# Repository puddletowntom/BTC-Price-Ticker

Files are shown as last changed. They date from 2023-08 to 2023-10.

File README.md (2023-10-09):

# Bitcoin Metrics Tracker



# Introduction

The Bitcoin metrics tracker was designed to sit near your desktop and keep an eye on several key important metrics on the Bitcoin network. These metrics include the Bitcoin price, the total Bitcoin marketcap, the total Bitcoin supply, the hash rate of the network, the current number of Bitcoins rewarded per block, the estimated time interval between blocks mined, the number of blocks mined so far and the remaining blocks left to mine in the current 4 year cycle. It uses Wi-Fi to connect to Blockchain.com to update the metrics at regular intervals. There is no need to hard code Wi-Fi credentials as there is a WPS setup for synchronisation with your router. Router credentials are then saved to flash memory via NVS so that you only have to do it one time. The green light on the screen indicates if Wi-Fi is connected. The green light will switch off if disconnected with the router. It will try to reconnect when it disconnects. The spinner around the green light is when the data is updating. 

# Parts Included

For the 3D printed case I have included the 3mf files. This project includes the following,

- RGB (565) display with ST7701s IC driver,
- ESP32-S3 R8 (8MB PSRAM) and 4MB of flash memory,
- Charging circuitry on PCB,
- USB-C,
- 3D print case

# Development Board

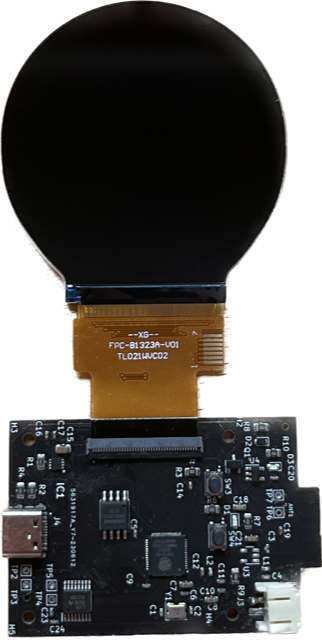
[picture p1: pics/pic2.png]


# Software 

- Kicad for PCB files,
- Fusion 360 for STL files,
- ESP-IDF for development environment,
- SquareLine Studio for display graphics

# Pinout

You can find the entire pinout with the schematic provided. But a brief overview is as follows,

Buttons

- TP6 to TP7 for Power button,
- SW3 - Reset button,
- SW4 - Boot button

# WPS

When you first turn on the device you will be met with the WPS screen. This is so you can connect to your router without needing to type your Wi-Fi credentials. So you need to press your WPS button on your router to sync it with the device. If it fails to move on from the WPS screen, unplug the device and plug it back in and press the WPS button on the router again. If it syncs with your router it will move on to the next screen which is a Bitcoin logo saying setup. 

# Programming the device

There are two modes for the ESP32-S3, download mode (upload program) and run mode (code running). To put the board in program mode press and hold the button SW4 (boot) and while this is still being held press the SW3 (reset) button. To put the board into run mode just press SW3 (reset) button once or alternatively just unplug the device. 

- idf.py set-target ESP32-S3 (only need to do this once)
- idf.py build (rebuild when you make changes to code)
- idf.py flash -p COM8 -b 921600 monitor (download code while monitoring)

# Restore credentials

If you want to change the Wi-Fi credentials to a new router, I have put in a define for restoring credentials. To do this you need to uncomment the following and build+download+run this code to clear credentials. 

#define CONFIG_RESTORE

You then need to comment it out again and download it to revert to original code. 

//#define CONFIG_RESTORE

# Further Work

The device currently doesnt have a GPIO reset button which means that once you sync the device with a Wi-Fi router via WPS you cant join a different router unless you reprogram the board with the config restore feature.

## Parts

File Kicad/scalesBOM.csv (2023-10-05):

Source: | C:\Users\ronan\Documents\KiCad\WSUpgrade\WeightingScales.kicad_sch
Date: | 10/06/2023 12:21:17
Tool: | Eeschema 7.0.1
Generator: | C:\Program Files\KiCad\7.0\bin\scripting\plugins/bom_csv_grouped_by_value_with_fp.py
Component Count: | 63
Ref | Qnty | Value | Cmp name | Footprint | Description | Vendor | DNP
AE1 | 1 | Antenna_Loop | Antenna_Loop | ESP_Antenna:ESPRESSIF_ESP32_MIFA_2.4GHz_Right | Loop antenna
C1, C2 | 2 | 22pF | C | Capacitor_SMD:C_0402_1005Metric | Unpolarized capacitor
C3, C4 | 2 | 3p3 | C | Capacitor_SMD:C_0402_1005Metric | Unpolarized capacitor
C5, C16 | 2 | 100nF | C | Capacitor_SMD:C_0402_1005Metric | Unpolarized capacitor
C6, C10, C17, C19 | 4 | 1uF | C | Capacitor_SMD:C_0402_1005Metric | Unpolarized capacitor
C7, C8 | 2 | 10uF | C | Capacitor_SMD:C_0603_1608Metric | Unpolarized capacitor
C9, C11, C12, C14, C23, C24 | 6 | 0.1uF | C | Capacitor_SMD:C_0402_1005Metric | Capacitor symbol for simulation only
C15 | 1 | 1uF | C | Capacitor_SMD:C_0805_2012Metric | Unpolarized capacitor
C18, C21 | 2 | 4.7uF | C | Capacitor_SMD:C_0603_1608Metric | Unpolarized capacitor
C20 | 1 | 2.2uF | C | Capacitor_SMD:C_0402_1005Metric | Unpolarized capacitor
D1, D3 | 2 | LED | LED | LED_SMD:LED_0603_1608Metric | Light emitting diode
D2 | 1 | D_Schottky | D_Schottky | Diode_SMD:D_0603_1608Metric | Schottky diode
H2, H3, H4, H5 | 4 | MountingHole | MountingHole | MountingHole:MountingHole_2.2mm_M2 | Mounting Hole without connection
IC1 | 1 | CAT4004AHU2-GT3 | CAT4004AHU2-GT3 | CAT4004A-libraries:SON50P200X200X55-9N | Driver,LED,4-channel,EZDim,UDFN8 ON Semiconductor CAT4004AHU2-GT3, LED Display Driver, 4 V, 8-Pin UDFN
IC2 | 1 | ADS1230IPWR | ADS1230IPWR | ADS1230IPWR:SOP65P640X120-16N | 20-Bit, 80SPS, 1-Ch Delta-Sigma ADC for Resistive Bridge Sensors & Weigh Scales
IC3 | 1 | ESP32-S3R8 | ESP32-S3R8 | ESP32-S3R8:QFN40P700X700X90-57N-D | WiFi Modules - 802.11 SMD IC, Dual-Core MCU, Wi-Fi 2.4G & BLE 5.0 Combo, 8 MB Octal SPI PSRAM, QFN 56-pin, 7*7 mm
J2 | 1 | FH34SRJ-40S-0.5SH(50) | FH34SRJ-40S-0.5SH(50) | FH34SRJ-40S-0.5SH_50_:HRS_FH34SRJ-40S-0.5SH(50)
J3 | 1 | Conn_01x02 | Conn_01x02 | Connector_JST:JST_PH_S2B-PH-SM4-TB_1x02-1MP_P2.00mm_Horizontal | Generic connector, single row, 01x02, script generated (kicad-library-utils/schlib/autogen/connector/)
J4 | 1 | TYPE-C-31-M-12 | TYPE-C-31-M-12 | TYPE-C-31-M-12:HRO_TYPE-C-31-M-12
L1 | 1 | 2n2 | L | Inductor_SMD:L_0402_1005Metric | Inductor
L2 | 1 | 2nH | L | Inductor_SMD:L_0402_1005Metric | Inductor
Q1 | 1 | AO3401A | AO3401A | Package_TO_SOT_SMD:SOT-23 | -4.0A Id, -30V Vds, P-Channel MOSFET, SOT-23
R1 | 1 | 3.74k | R | Resistor_SMD:R_0805_2012Metric | Resistor
R2, R4 | 2 | 5.1k | R | Resistor_SMD:R_0805_2012Metric | Resistor
R3, R6, R8 | 3 | 10k | R | Resistor_SMD:R_0805_2012Metric | Resistor
R7, R10 | 2 | 1k | R | Resistor_SMD:R_0805_2012Metric | Resistor
R9 | 1 | 2k | R | Resistor_SMD:R_0805_2012Metric | Resistor
SW3, SW4 | 2 | PTS810_SJM_250_SMTR_LFS | PTS810_SJM_250_SMTR_LFS | PTS810_SJM_250_SMTR_LFS:SW_PTS810_SJM_250_SMTR_LFS
TP1, TP2, TP3, TP4, TP5, TP6, TP7, TP19, TP20 | 9 | TestPoint | TestPoint | Connector_Pin:Pin_D0.7mm_L6.5mm_W1.8mm_FlatFork | test point
U2 | 1 | W25Q32JVSS | W25Q32JVSS | Package_SO:SOIC-8_5.23x5.23mm_P1.27mm | 32Mb Serial Flash Memory, Standard/Dual/Quad SPI, SOIC-8
U3 | 1 | MCP73831-3-OT | MCP73831-3-OT | Package_TO_SOT_SMD:SOT-23-5 | Single cell, Li-Ion/Li-Po charge management controller, 4.35V, Tri-State Status Output, in SOT23-5 package
U4 | 1 | AP2112K-3.3 | AP2112K-3.3 | Package_TO_SOT_SMD:SOT-23-5 | 600mA low dropout linear regulator, with enable pin, 3.8V-6V input voltage range, 3.3V fixed positive output, SOT-23-5
Y1 | 1 | 40MHz | Crystal_GND24 | Crystal:Crystal_SMD_3225-4Pin_3.2x2.5mm | Four pin crystal, GND on pins 2 and 4

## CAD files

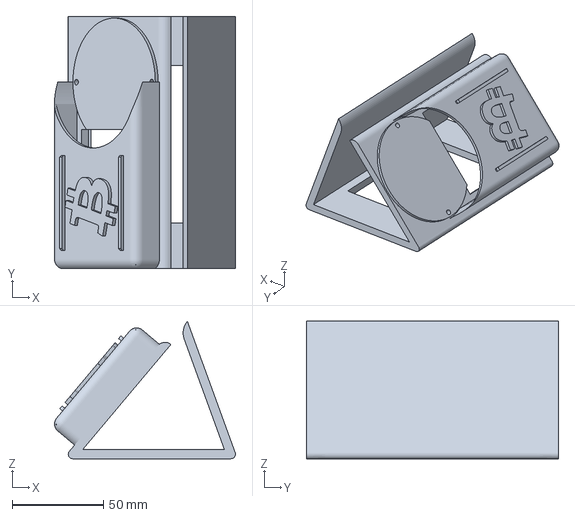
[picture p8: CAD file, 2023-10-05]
3mf/btc_tracker.3mf
98.9 x 138.0 x 75.2 mm

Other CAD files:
cad/btc_tracker.f3d

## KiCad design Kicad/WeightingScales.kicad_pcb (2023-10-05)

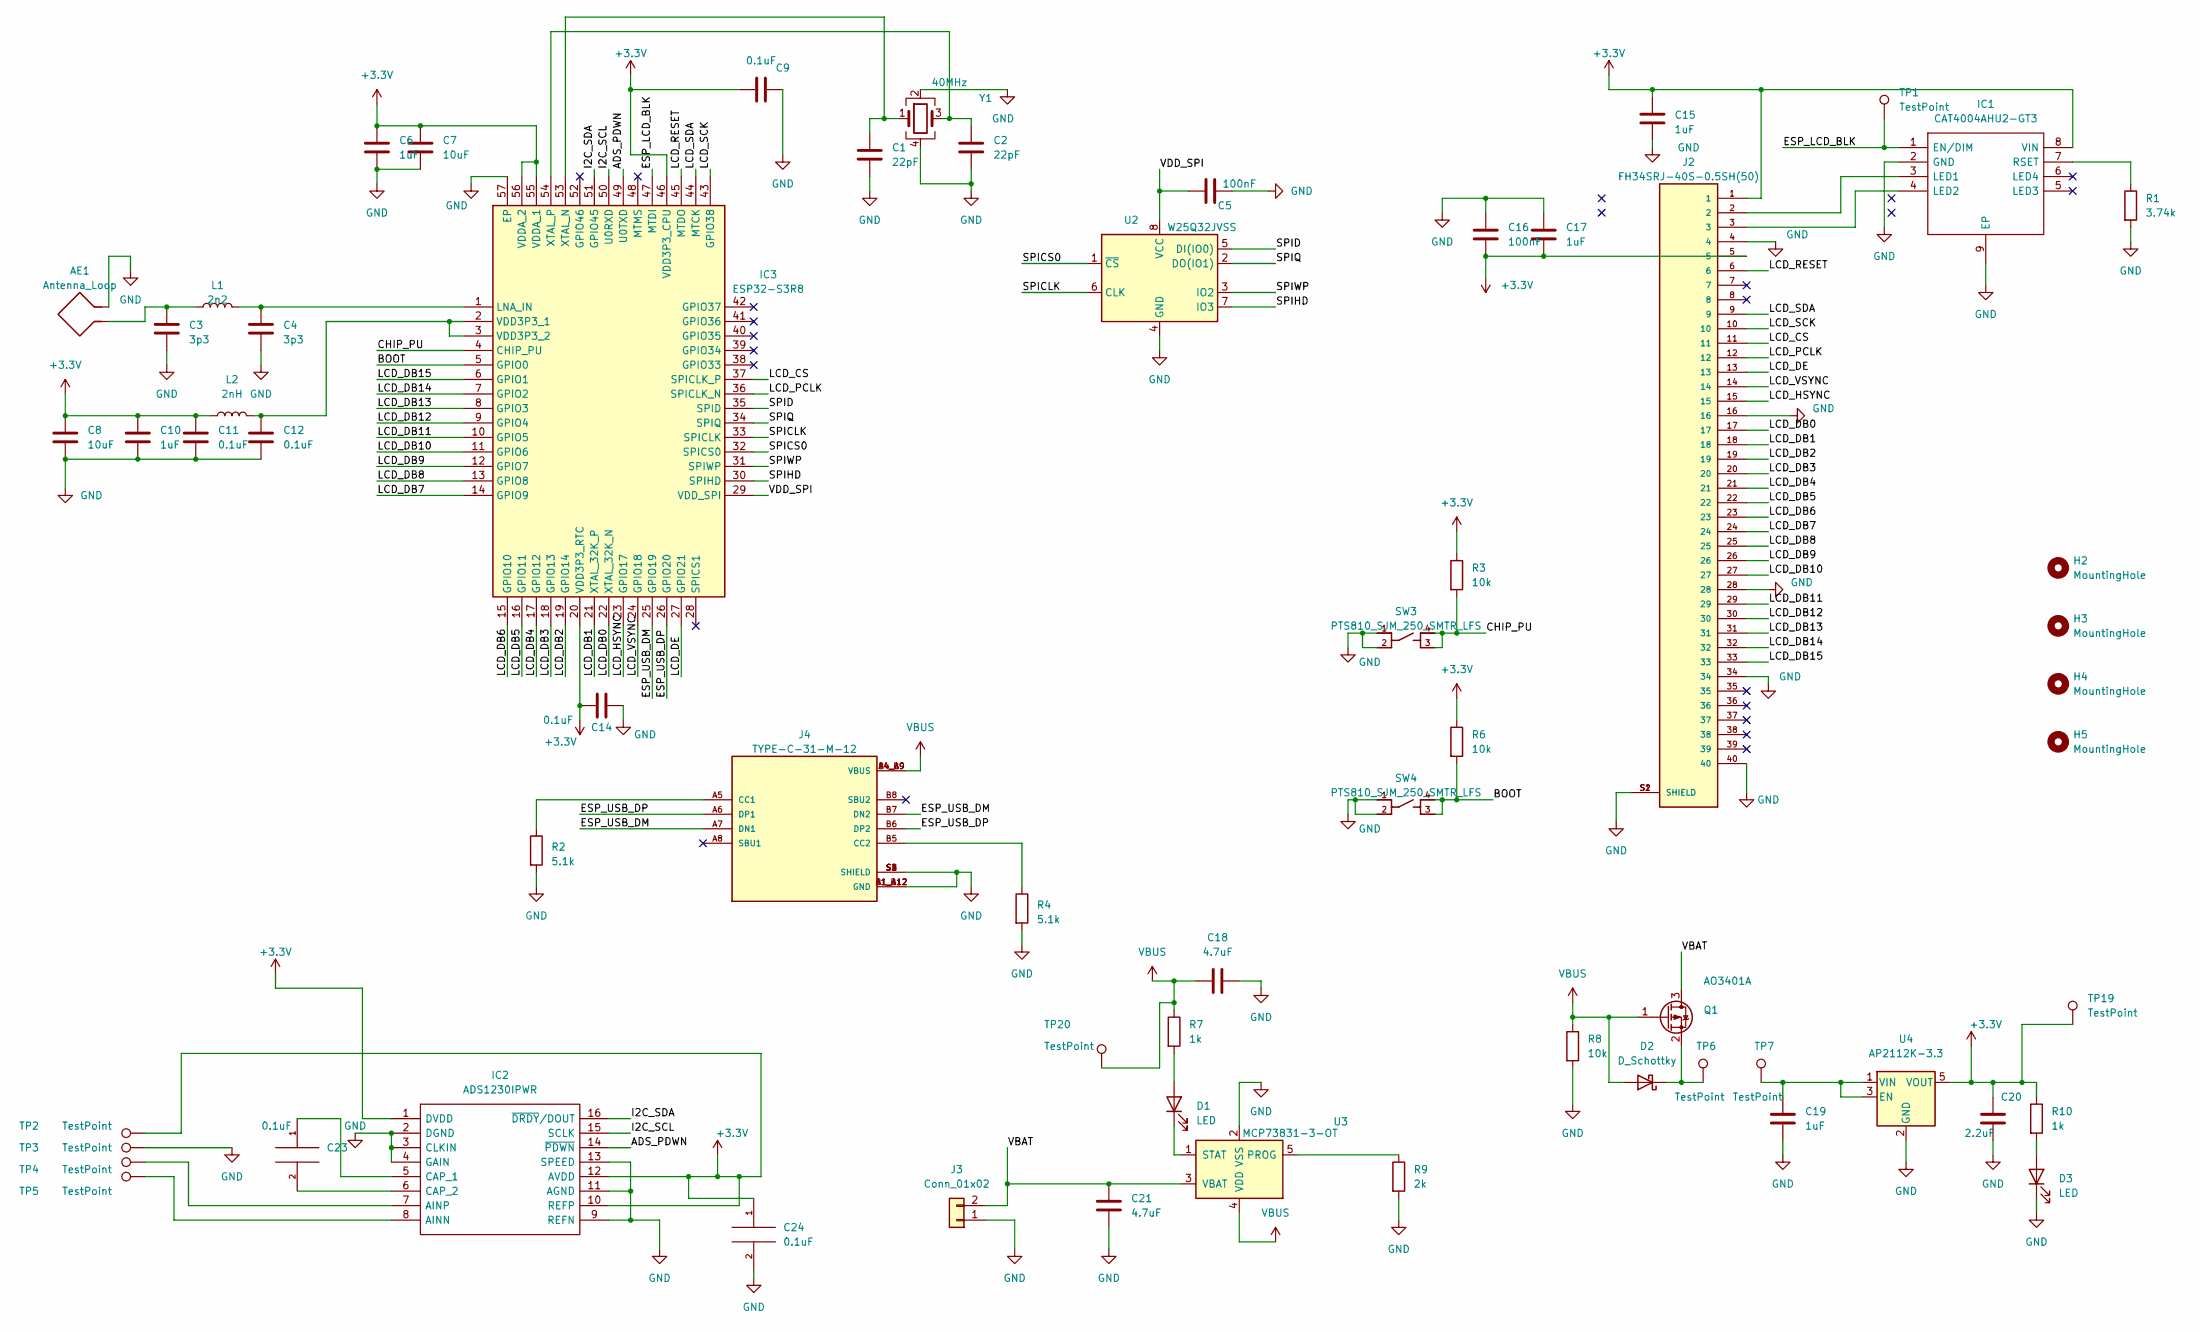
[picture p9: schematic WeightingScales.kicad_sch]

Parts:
AE1: Antenna_Loop; ESPRESSIF_ESP32_MIFA_2.4GHz_Right
C1, C2: 22pF; C_0402_1005Metric
C3, C4: 3p3; C_0402_1005Metric
C5, C16: 100nF; C_0402_1005Metric
C6, C10, C17, C19: 1uF; C_0402_1005Metric
C7, C8: 10uF; C_0603_1608Metric
C9, C11, C12, C14, C23, C24: 0.1uF; C_0402_1005Metric
C15: 1uF; C_0805_2012Metric
C18, C21: 4.7uF; C_0603_1608Metric
C20: 2.2uF; C_0402_1005Metric
D1, D3: LED; LED_0603_1608Metric
D2: D_Schottky; D_0603_1608Metric
H2, H3, H4, H5: MountingHole; MountingHole_2.2mm_M2
IC1: CAT4004AHU2-GT3; SON50P200X200X55-9N; Mouser Part Number 863-CAT4004AHU2-GT3
IC2: ADS1230IPWR; SOP65P640X120-16N; Mouser Part Number 595-ADS1230IPWR
IC3: ESP32-S3R8; QFN40P700X700X90-57N-D; Mouser Part Number 356-ESP32-S3R8
J2: FH34SRJ-40S-0.5SH(50); HRS_FH34SRJ-40S-0.5SH(50)
J3: Conn_01x02; JST_PH_S2B-PH-SM4-TB_1x02-1MP_P2.00mm_Horizontal
J4: TYPE-C-31-M-12; HRO_TYPE-C-31-M-12; PARTREV 2020.12.08
L1: 2n2; L_0402_1005Metric
L2: 2nH; L_0402_1005Metric
Q1: AO3401A; SOT-23
R1: 3.74k; R_0805_2012Metric
R2, R4: 5.1k; R_0805_2012Metric
R3, R6, R8: 10k; R_0805_2012Metric
R7, R10: 1k; R_0805_2012Metric
R9: 2k; R_0805_2012Metric
SW3, SW4: PTS810_SJM_250_SMTR_LFS; SW_PTS810_SJM_250_SMTR_LFS
TP1, TP2, TP3, TP4, TP5, TP6, TP7, TP19, TP20: TestPoint; Pin_D0.7mm_L6.5mm_W1.8mm_FlatFork
U2: W25Q32JVSS; SOIC-8_5.23x5.23mm_P1.27mm
U3: MCP73831-3-OT; SOT-23-5
U4: AP2112K-3.3; SOT-23-5
Y1: 40MHz; Crystal_SMD_3225-4Pin_3.2x2.5mm

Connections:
+3.3V: C6.1, C7.1, C8.1, C9.1, C10.1, C11.1, C14.1, C15.2, C16.2, C17.2, C20.1, C24.1, IC1.8 (VIN), IC2.1 (DVDD), IC2.10 (REFP), IC2.12 (AVDD), IC3.20 (VDD3P3_RTC), IC3.46 (VDD3P3_CPU), IC3.55 (VDDA_1), IC3.56 (VDDA_2), J2.1, J2.5, L2.1, R3.1, R6.1, R10.1, TP2.1, TP19.1, U4.5 (VOUT)
/ADS_PDWN: IC2.14 (~PDWN), IC3.49 (U0TXD)
/BOOT: IC3.5 (GPIO0), R6.2, SW4.3, SW4.4
/CHIP_PU: IC3.4 (CHIP_PU), R3.2, SW3.3, SW3.4
/ESP_LCD_BLK: IC1.1 (EN/DIM), IC3.47 (MTDI), TP1.1
/ESP_USB_DM: IC3.25 (GPIO19), J4.A7 (DN1), J4.B7 (DN2)
/ESP_USB_DP: IC3.26 (GPIO20), J4.A6 (DP1), J4.B6 (DP2)
/I2C_SCL: IC2.15 (SCLK), IC3.50 (U0RXD)
/I2C_SDA: IC2.16 (~DRDY/DOUT), IC3.51 (GPIO45)
/LCD_CS: IC3.37 (SPICLK_P), J2.11
/LCD_DB0: IC3.22 (XTAL_32K_N), J2.17
/LCD_DB1: IC3.21 (XTAL_32K_P), J2.18
/LCD_DB2: IC3.19 (GPIO14), J2.19
/LCD_DB3: IC3.18 (GPIO13), J2.20
/LCD_DB4: IC3.17 (GPIO12), J2.21
/LCD_DB5: IC3.16 (GPIO11), J2.22
/LCD_DB6: IC3.15 (GPIO10), J2.23
/LCD_DB7: IC3.14 (GPIO9), J2.24
/LCD_DB8: IC3.13 (GPIO8), J2.25
/LCD_DB9: IC3.12 (GPIO7), J2.26
/LCD_DB10: IC3.11 (GPIO6), J2.27
/LCD_DB11: IC3.10 (GPIO5), J2.29
/LCD_DB12: IC3.9 (GPIO4), J2.30
/LCD_DB13: IC3.8 (GPIO3), J2.31
/LCD_DB14: IC3.7 (GPIO2), J2.32
/LCD_DB15: IC3.6 (GPIO1), J2.33
/LCD_DE: IC3.27 (GPIO21), J2.13
/LCD_HSYNC: IC3.23 (GPIO17), J2.15
/LCD_PCLK: IC3.36 (SPICLK_N), J2.12
/LCD_RESET: IC3.45 (MTDO), J2.6
/LCD_SCK: IC3.43 (GPIO38), J2.10
/LCD_SDA: IC3.44 (MTCK), J2.9
/LCD_VSYNC: IC3.24 (GPIO18), J2.14
/SPICLK: IC3.33 (SPICLK), U2.6 (CLK)
/SPICS0: IC3.32 (SPICS0), U2.1 (~CS)
/SPID: IC3.35 (SPID), U2.5 (DI(IO0))
/SPIHD: IC3.30 (SPIHD), U2.7 (IO3)
/SPIQ: IC3.34 (SPIQ), U2.2 (DO(IO1))
/SPIWP: IC3.31 (SPIWP), U2.3 (IO2)
/VBAT: C21.1, J3.2, Q1.3 (D), U3.3 (VBAT)
/VDD_SPI: C5.1, IC3.29 (VDD_SPI), U2.8 (VCC)
GND: AE1.2, C1.2, C2.2, C3.2, C4.2, C5.2, C6.2, C7.2, C8.2, C9.2, C10.2, C11.2, C12.2, C14.2, C15.1, C16.1, C17.1, C18.2, C19.2, C20.2, C21.2, C24.2, D3.1 (K), IC1.2 (GND), IC1.9 (EP), IC2.2 (DGND), IC2.3 (CLKIN), IC2.4 (GAIN), IC2.9 (REFN), IC2.11 (AGND), IC2.13 (SPEED), IC3.57 (EP), J2.4, J2.16, J2.28, J2.34, J2.40, J2.S1 (SHIELD), J2.S2 (SHIELD), J3.1, J4.A1_B12 (GND), J4.B1_A12 (GND), J4.S1 (SHIELD), J4.S2 (SHIELD), J4.S3 (SHIELD), J4.S4 (SHIELD), R1.2, R2.2, R4.2, R8.2, R9.2, SW3.1, SW3.2, SW4.1, SW4.2, TP3.1, U2.4 (GND), U3.2 (VSS), U4.2 (GND), Y1.2, Y1.4; also elsewhere on the board
unnamed 42: AE1.1, C3.1, L1.1; also elsewhere on the board
unnamed: D1.2 (A), R7.2
unnamed: D1.1 (K), U3.1 (STAT)
unnamed: D2.1 (K), Q1.2 (S), TP6.1
unnamed: D3.2 (A), R10.2
unnamed: IC1.3 (LED1), J2.2
unnamed: IC1.4 (LED2), J2.3
unnamed: IC1.7 (RSET), R1.1
unnamed: IC2.8 (AINN), TP5.1
unnamed: IC2.7 (AINP), TP4.1
unnamed: C23.1, IC2.5 (CAP_1)
unnamed: C23.2, IC2.6 (CAP_2)
unnamed: C4.1, IC3.1 (LNA_IN), L1.2
unnamed: C12.1, IC3.2 (VDD3P3_1), IC3.3 (VDD3P3_2), L2.2
unnamed: C1.1, IC3.53 (XTAL_N), Y1.1
unnamed: C2.1, IC3.54 (XTAL_P), Y1.3
unnamed: J4.A5 (CC1), R2.1
unnamed: J4.B5 (CC2), R4.1
unnamed: R9.1, U3.5 (PROG)
unnamed: C19.1, TP7.1, U4.1 (VIN), U4.3 (EN)
VBUS: C18.1, D2.2 (A), J4.A4_B9 (VBUS), J4.B4_A9 (VBUS), Q1.1 (G), R7.1, R8.1, TP20.1, U3.4 (VDD)

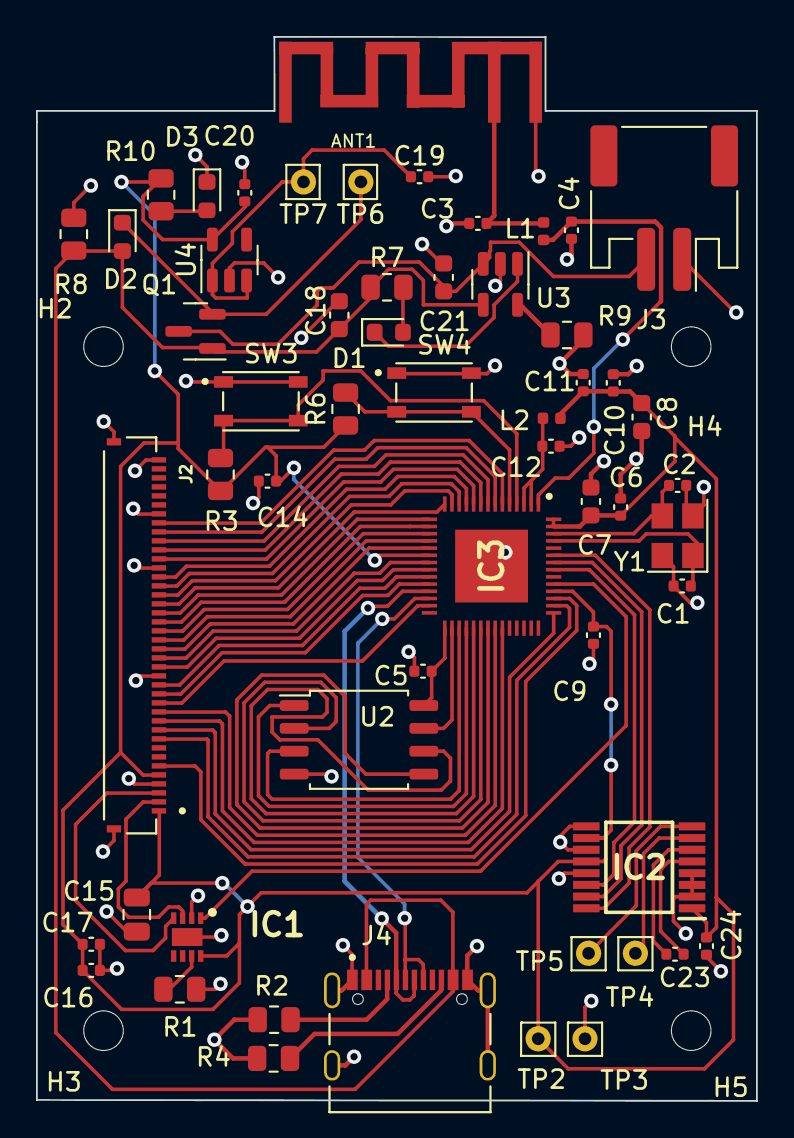
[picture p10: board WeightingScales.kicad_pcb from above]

Board: 2 copper layers, 40.0 x 59.1 mm, 60 parts (0 on the bottom side), 63 nets.

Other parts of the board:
ANT1: PCB_ANT; PCB_Antenna_2_4_GHz_ESP32

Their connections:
GND: ANT1.2; also elsewhere on the board
unnamed 42: ANT1.1; also elsewhere on the board

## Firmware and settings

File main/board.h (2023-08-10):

#pragma once

// RGB SPI interface
#define LCD_SPI_DATA0     39  /*!< for 1-line SPI, this also refered as MOSI */
#define LCD_SPI_CLK       38
#define LCD_SPI_CS        47
#define LCD_SPI_DC        -1
#define LCD_SPI_RST       40

// RGB interface
#define LCD_PCLK_GPIO     (48)
#define LCD_VSYNC_GPIO    (18)
#define LCD_HSYNC_GPIO    (17)
#define LCD_DE_GPIO       (21)

#define RGB_B0       (16)  // B0
#define RGB_B1       (15)  // B1
#define RGB_B2       (14)   // B2
#define RGB_B3       (13)  // B3
#define RGB_B4       (12)  // B4
#define RGB_G0       (11)   // G0
#define RGB_G1       (10)  // G1
#define RGB_G2       (9)  // G2
#define RGB_G3       (8)  // G3
#define RGB_G4       (7)  // G4
#define RGB_G5      (6)  // G5
#define RGB_R0      (5)  // R0
#define RGB_R1      (4)  // R1
#define RGB_R2      (3)   // R2
#define RGB_R3      (2)  // R3
#define RGB_R4      (1)  // R4

#define LCD_DATA0_GPIO    (RGB_B0)   // B0
#define LCD_DATA1_GPIO    (RGB_B1)   // B1
#define LCD_DATA2_GPIO    (RGB_B2)   // B2
#define LCD_DATA3_GPIO    (RGB_B3)   // B3
#define LCD_DATA4_GPIO    (RGB_B4)   // B4
#define LCD_DATA5_GPIO    (RGB_G0)   // G0
#define LCD_DATA6_GPIO    (RGB_G1)    // G1
#define LCD_DATA7_GPIO    (RGB_G2)   // G2
#define LCD_DATA8_GPIO    (RGB_G3)   // G3
#define LCD_DATA9_GPIO    (RGB_G4)   // G4
#define LCD_DATA10_GPIO   (RGB_G5)   // G5
#define LCD_DATA11_GPIO   (RGB_R0)   // R0
#define LCD_DATA12_GPIO   (RGB_R1)    // R1
#define LCD_DATA13_GPIO   (RGB_R2)    // R2
#define LCD_DATA14_GPIO   (RGB_R3)    // R3
#define LCD_DATA15_GPIO   (RGB_R4)    // R4
#define LCD_DISP_EN_GPIO  (-1)

#define LCD_PIN_BK_LIGHT       41

#define LCD_BK_LIGHT_ON_LEVEL  1
#define LCD_BK_LIGHT_OFF_LEVEL !LCD_BK_LIGHT_ON_LEVEL

//#define ENCODER_A_PIN     (5)
//#define ENCODER_B_PIN     (6)

//#define MOTOR_PIN         (7)
//#define LED_PIN           (4)

//#define BTN_PIN           (3)

//#define EXT_PIN_0         (1)
//#define EXT_PIN_1         (2)
//#define EXT_PIN_2         (20)
//#define EXT_PIN_3         (19)

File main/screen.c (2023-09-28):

#include <stdio.h>
#include <string.h>
#include "freertos/FreeRTOS.h"
#include "freertos/task.h"
#include "freertos/queue.h"
#include "freertos/semphr.h"
#include "soc/soc_caps.h"
#include "esp_freertos_hooks.h"
#include "esp_log.h"
#include "esp_lcd_panel_io.h"
#include "esp_lcd_panel_vendor.h"
#include "esp_lcd_panel_ops.h"
#include "esp_lcd_panel_interface.h"
#include "esp_lcd_panel_rgb.h"
#include "driver/gpio.h"
#include "board.h"
#include "lvgl.h"
#include "esp_timer.h"
#include "driver/spi_master.h"

#define TAG "RGB"

#define ECO_O(y) (y>0)? -1:1
#define ECO_STEP(x) x? ECO_O(x):0

static esp_lcd_panel_handle_t g_panel_handle = NULL;

static void increase_lvgl_tick(void* arg) {
    lv_tick_inc(portTICK_PERIOD_MS);
}

static void __qsmd_rgb_disp_flush(lv_disp_drv_t *disp_drv, const lv_area_t *area, lv_color_t *color_p)
{
    int offsetx1 = area->x1;
    int offsetx2 = area->x2;
    int offsety1 = area->y1;
    int offsety2 = area->y2;

    esp_lcd_panel_draw_bitmap(g_panel_handle, offsetx1, offsety1, offsetx2 + 1, offsety2 + 1, color_p);
    lv_disp_flush_ready(disp_drv);
}

void qmsd_rgb_init(esp_lcd_rgb_panel_config_t *panel_config)
{
    static lv_disp_drv_t disp_drv;
    int buffer_size;
    void *buf1 = NULL;
    void *buf2 = NULL;
	static lv_disp_draw_buf_t draw_buf;

    lv_init();

    ESP_ERROR_CHECK(esp_lcd_new_rgb_panel(panel_config, &g_panel_handle));
    ESP_ERROR_CHECK(esp_lcd_panel_reset(g_panel_handle));
    ESP_ERROR_CHECK(esp_lcd_panel_init(g_panel_handle));

    buffer_size = 480 * 40;
	buf1 = heap_caps_malloc(buffer_size*2, MALLOC_CAP_DMA);
	//buf2 = heap_caps_malloc(buffer_size*2, MALLOC_CAP_DMA);

    lv_disp_draw_buf_init(&draw_buf, buf1, buf2, buffer_size);

    lv_disp_drv_init(&disp_drv);         
    disp_drv.flush_cb = __qsmd_rgb_disp_flush;
    disp_drv.draw_buf = &draw_buf;
    disp_drv.hor_res = panel_config->timings.h_res;
    disp_drv.ver_res = panel_config->timings.v_res;
	//disp_drv.rotated = LV_DISP_ROT_90; //Flip display 90 degrees to the right for USB stand.
	//disp_drv.sw_rotate = 1;
    lv_disp_drv_register(&disp_drv); //
}

static spi_device_handle_t g_screen_spi;

static void lcd_cmd(spi_device_handle_t spi, const uint16_t data) {
    esp_err_t ret;
    uint16_t tmp_cmd =(data | 0x0000);
    spi_transaction_ext_t trans =(spi_transaction_ext_t) {
        .base = {
            .flags = SPI_TRANS_VARIABLE_CMD,
            .cmd = tmp_cmd,
        },
        .command_bits = 9,
    };
    ret = spi_device_transmit(spi,(spi_transaction_t *)&trans);
    assert(ret == ESP_OK);          //Should have had no issues.
}

static void lcd_data(spi_device_handle_t spi, const uint16_t data) {
    esp_err_t ret;
    uint16_t tmp_cmd =(data | 0x0100);
    spi_transaction_ext_t trans =(spi_transaction_ext_t) {
        .base = {
            .flags = SPI_TRANS_VARIABLE_CMD,
            .cmd = tmp_cmd,
        },
        .command_bits = 9,
    };
    ret = spi_device_transmit(spi,(spi_transaction_t *)&trans);

    assert(ret == ESP_OK);          //Should have had no issues.
}

static void SPI_WriteComm(uint16_t cmd) {
    lcd_cmd(g_screen_spi, cmd);
}

static void SPI_WriteData(uint16_t data) {
    lcd_data(g_screen_spi, data);
}

static void rgb_driver_init(void) {
	SPI_WriteComm(0xFF);
	SPI_WriteData(0x77);
	SPI_WriteData(0x01);
	SPI_WriteData(0x00);
	SPI_WriteData(0x00);
	SPI_WriteData(0x13);
	SPI_WriteComm(0xEF);
	SPI_WriteData(0x08);

	SPI_WriteComm(0xFF);
	SPI_WriteData(0x77);
	SPI_WriteData(0x01);
	SPI_WriteData(0x00);
	SPI_WriteData(0x00);
	SPI_WriteData(0x10);

	SPI_WriteComm(0xC0);
	SPI_WriteData(0x3B);//Scan line	
	SPI_WriteData(0x00);

	SPI_WriteComm(0xC1);
	SPI_WriteData(0x0B);	//VBP
	SPI_WriteData(0x02);

	SPI_WriteComm(0xC2);
	SPI_WriteData(0x07);
	SPI_WriteData(0x02);

	SPI_WriteComm(0xCC);
	SPI_WriteData(0x10);

	SPI_WriteComm(0xCD);//RGB format
	SPI_WriteData(0x08);        //?565???    666??

	SPI_WriteComm(0xB0); // IPS   
	SPI_WriteData(0x00); // 255 
	SPI_WriteData(0x11); // 251    
	SPI_WriteData(0x16); // 247  down
	SPI_WriteData(0x0e); // 239    
	SPI_WriteData(0x11); // 231    
	SPI_WriteData(0x06); // 203    
	SPI_WriteData(0x05); // 175 
	SPI_WriteData(0x09); // 147    
	SPI_WriteData(0x08); // 108    
	SPI_WriteData(0x21); // 80  
	SPI_WriteData(0x06); // 52   
	SPI_WriteData(0x13); // 24    
	SPI_WriteData(0x10); // 16    
	SPI_WriteData(0x29); // 8    down
	SPI_WriteData(0x31); // 4    
	SPI_WriteData(0x18); // 0   

	SPI_WriteComm(0xB1);//  IPS	   
	SPI_WriteData(0x00);//  255 
	SPI_WriteData(0x11);//  251
	SPI_WriteData(0x16);//  247   down
	SPI_WriteData(0x0e);//  239
	SPI_WriteData(0x11);//  231
	SPI_WriteData(0x07);//  203    
	SPI_WriteData(0x05);//  175
	SPI_WriteData(0x09);//  147  
	SPI_WriteData(0x09);//  108  
	SPI_WriteData(0x21);//  80 
	SPI_WriteData(0x05);//  52   
	SPI_WriteData(0x13);//  24 
	SPI_WriteData(0x11);//  16 
	SPI_WriteData(0x2a);//  8  down 
	SPI_WriteData(0x31);//  4  
	SPI_WriteData(0x18);//  0  

	SPI_WriteComm(0xFF);
	SPI_WriteData(0x77);
	SPI_WriteData(0x01);
	SPI_WriteData(0x00);
	SPI_WriteData(0x00);
	SPI_WriteData(0x11);

	SPI_WriteComm(0xB0);  //VOP  3.5375+ *x 0.0125
	SPI_WriteData(0x6d);  //5D
	
	SPI_WriteComm(0xB1); 	//VCOM amplitude setting  
	SPI_WriteData(0x37);  //
	
	SPI_WriteComm(0xB2); 	//VGH Voltage setting  
	SPI_WriteData(0x81);	//12V

	SPI_WriteComm(0xB3);
	SPI_WriteData(0x80);

	SPI_WriteComm(0xB5); 	//VGL Voltage setting  
	SPI_WriteData(0x43);	//-8.3V

	SPI_WriteComm(0xB7);
	SPI_WriteData(0x85);

	SPI_WriteComm(0xB8);
	SPI_WriteData(0x20);

	SPI_WriteComm(0xC1);
	SPI_WriteData(0x78);

	SPI_WriteComm(0xC2);
	SPI_WriteData(0x78);

	SPI_WriteComm(0xD0);
	SPI_WriteData(0x88);

	SPI_WriteComm(0xE0);
	SPI_WriteData(0x00);
	SPI_WriteData(0x00);
	SPI_WriteData(0x02);

	SPI_WriteComm(0xE1);
	SPI_WriteData(0x03);	
	SPI_WriteData(0xA0);
	SPI_WriteData(0x00);	
	SPI_WriteData(0x00);
	SPI_WriteData(0x04);	
	SPI_WriteData(0xA0);
	SPI_WriteData(0x00);	
	SPI_WriteData(0x00);	
	SPI_WriteData(0x00);
	SPI_WriteData(0x20);
	SPI_WriteData(0x20);

	SPI_WriteComm(0xE2);
	SPI_WriteData(0x00);	
	SPI_WriteData(0x00);	  
	SPI_WriteData(0x00);	
	SPI_WriteData(0x00);	
	SPI_WriteData(0x00);	
	SPI_WriteData(0x00);	
	SPI_WriteData(0x00);	
	SPI_WriteData(0x00);	
	SPI_WriteData(0x00);	
	SPI_WriteData(0x00);	
	SPI_WriteData(0x00);	
	SPI_WriteData(0x00);	
	SPI_WriteData(0x00);

	SPI_WriteComm(0xE3);
	SPI_WriteData(0x00);
	SPI_WriteData(0x00);
	SPI_WriteData(0x11);
	SPI_WriteData(0x00);

	SPI_WriteComm(0xE4);
	SPI_WriteData(0x22);
	SPI_WriteData(0x00);

	SPI_WriteComm(0xE5);		
	SPI_WriteData(0x05);	
	SPI_WriteData(0xEC);	
	SPI_WriteData(0xA0);
	SPI_WriteData(0xA0);
	SPI_WriteData(0x07);	
	SPI_WriteData(0xEE);	
	SPI_WriteData(0xA0);
	SPI_WriteData(0xA0);
	SPI_WriteData(0x00);
	SPI_WriteData(0x00);	
	SPI_WriteData(0x00);
	SPI_WriteData(0x00);
	SPI_WriteData(0x00);
	SPI_WriteData(0x00);	
	SPI_WriteData(0x00);
	SPI_WriteData(0x00);
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

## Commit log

2023-08-10 BTC price ticker for round display
    [partitions_lvgl.csv]
2023-08-21 Stats screen operational with real values
    [partitions_lvgl.csv]
2023-09-14 Edge case for WPS if stored config fails run WPS
2023-09-19 Exahash suffix added
    [partitions_lvgl.csv]
2023-09-21 Added Wi-Fi connection indicator and spindle for requests
2023-09-26 Better btc price ticker used (faster updating), fixed bug WPS (starts on first try rather than two tries)
    [screen.c]
2023-10-05 update to the README file
    [WeightingScales.kicad_pcb, WeightingScales.kicad_sch, all.3mf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]
2023-10-05 update to README
    [all.3mf, base.3mf, btc_tracker.3mf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]
2023-10-11 f3d file added
    [btc_tracker.f3d]
